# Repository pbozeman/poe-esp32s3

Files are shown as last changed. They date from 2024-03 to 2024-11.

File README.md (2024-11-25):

# POE ESP32S3

POE enabled ESP32S3 dev board with onboard programming via USB-C,
and an OTG USB-A port. The repo contains the Kicad schematic and PCB
design.

It is ok to apply power via USB-C and POE simultaneously. The board
gives preference to the POE, if it is present.

While this can be used as a general purpose POE dev board, I personally
use it to network enable a Aeotec Zwave stick using the ser2net protocol.

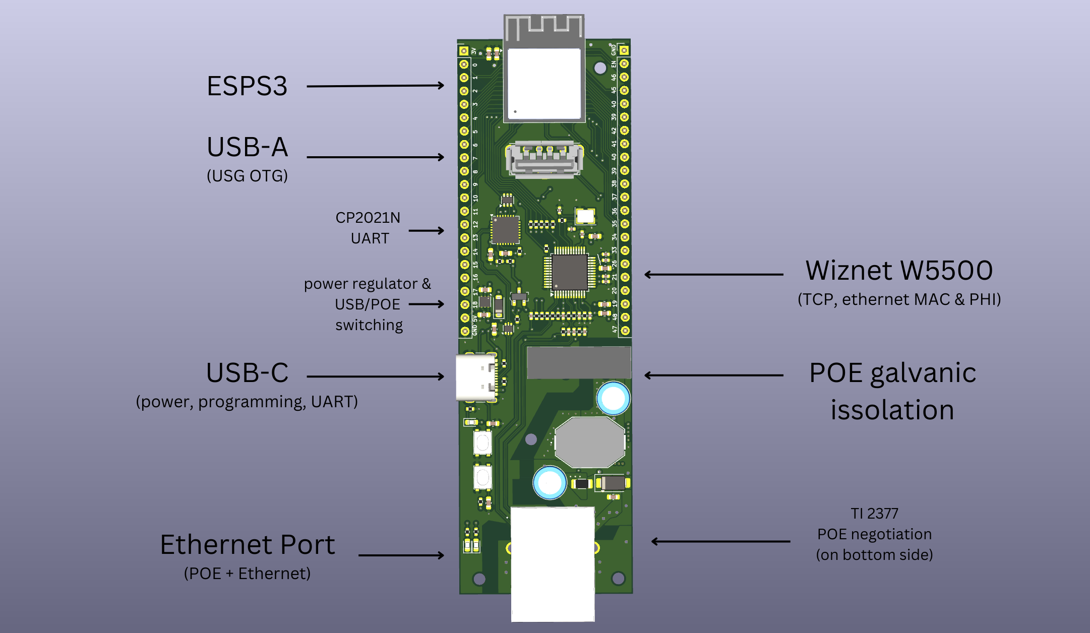
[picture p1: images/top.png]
top_pcb_image top pcb image


## "Inspiration"

I copied the POE schematic and layout directly from [OLIMEX](https://github.com/OLIMEX/ESP32-POE-ISO/blob/master/HARDWARE/ESP32-PoE-ISO-Rev.K/ESP32-PoE-ISO_Rev_K.pdf).

The Wiznet 5500 ethernet to SPI circuit was copied directly from the
[WS5500 reference circuit](https://docs.wiznet.io/img/products/w5500/W5500_ds_v110e.pdf)

Everything else is from the [ES32-S3 reference circuit](https://dl.espressif.com/dl/schematics/SCH_ESP32-S3-DEVKITM-1_V1_20210310A.pdf).

## General Caveats

This was my very first PCB and there is a lot I don't like about both
the schematic and the PCB layout. I'm only making this repo public
because someone on Reddit asked for the Kicad files.

More importantly, the Olimex POE design is very noisy. It's fine for
my use, but I heard from someone else that used an Olimex like design
that it was too noisy to use directly with an ADC.

If I were to do this again, I would base the POE design around Silvertel
POE modules, potentially using them directly. I measured one and it's
power was far less noisy. The entire unit is cheaper than trying to
source individual parts, and they come in form factors that should be easy
to integrate.

## Production and Update Caveats

I don't think part numbers were populated, and this may nor may not
seamlessly export with the JLCPCB exporter. The library management
is likely bad, and there is a possibility that I edited symbols or
footprints directly, without doing so in the library. There might
be non-relative paths in the library configs as well. I hadn't yet
established best practices for any of that back when I did this. So,
updating symbols and footprints might mess up the schematic and PCB.

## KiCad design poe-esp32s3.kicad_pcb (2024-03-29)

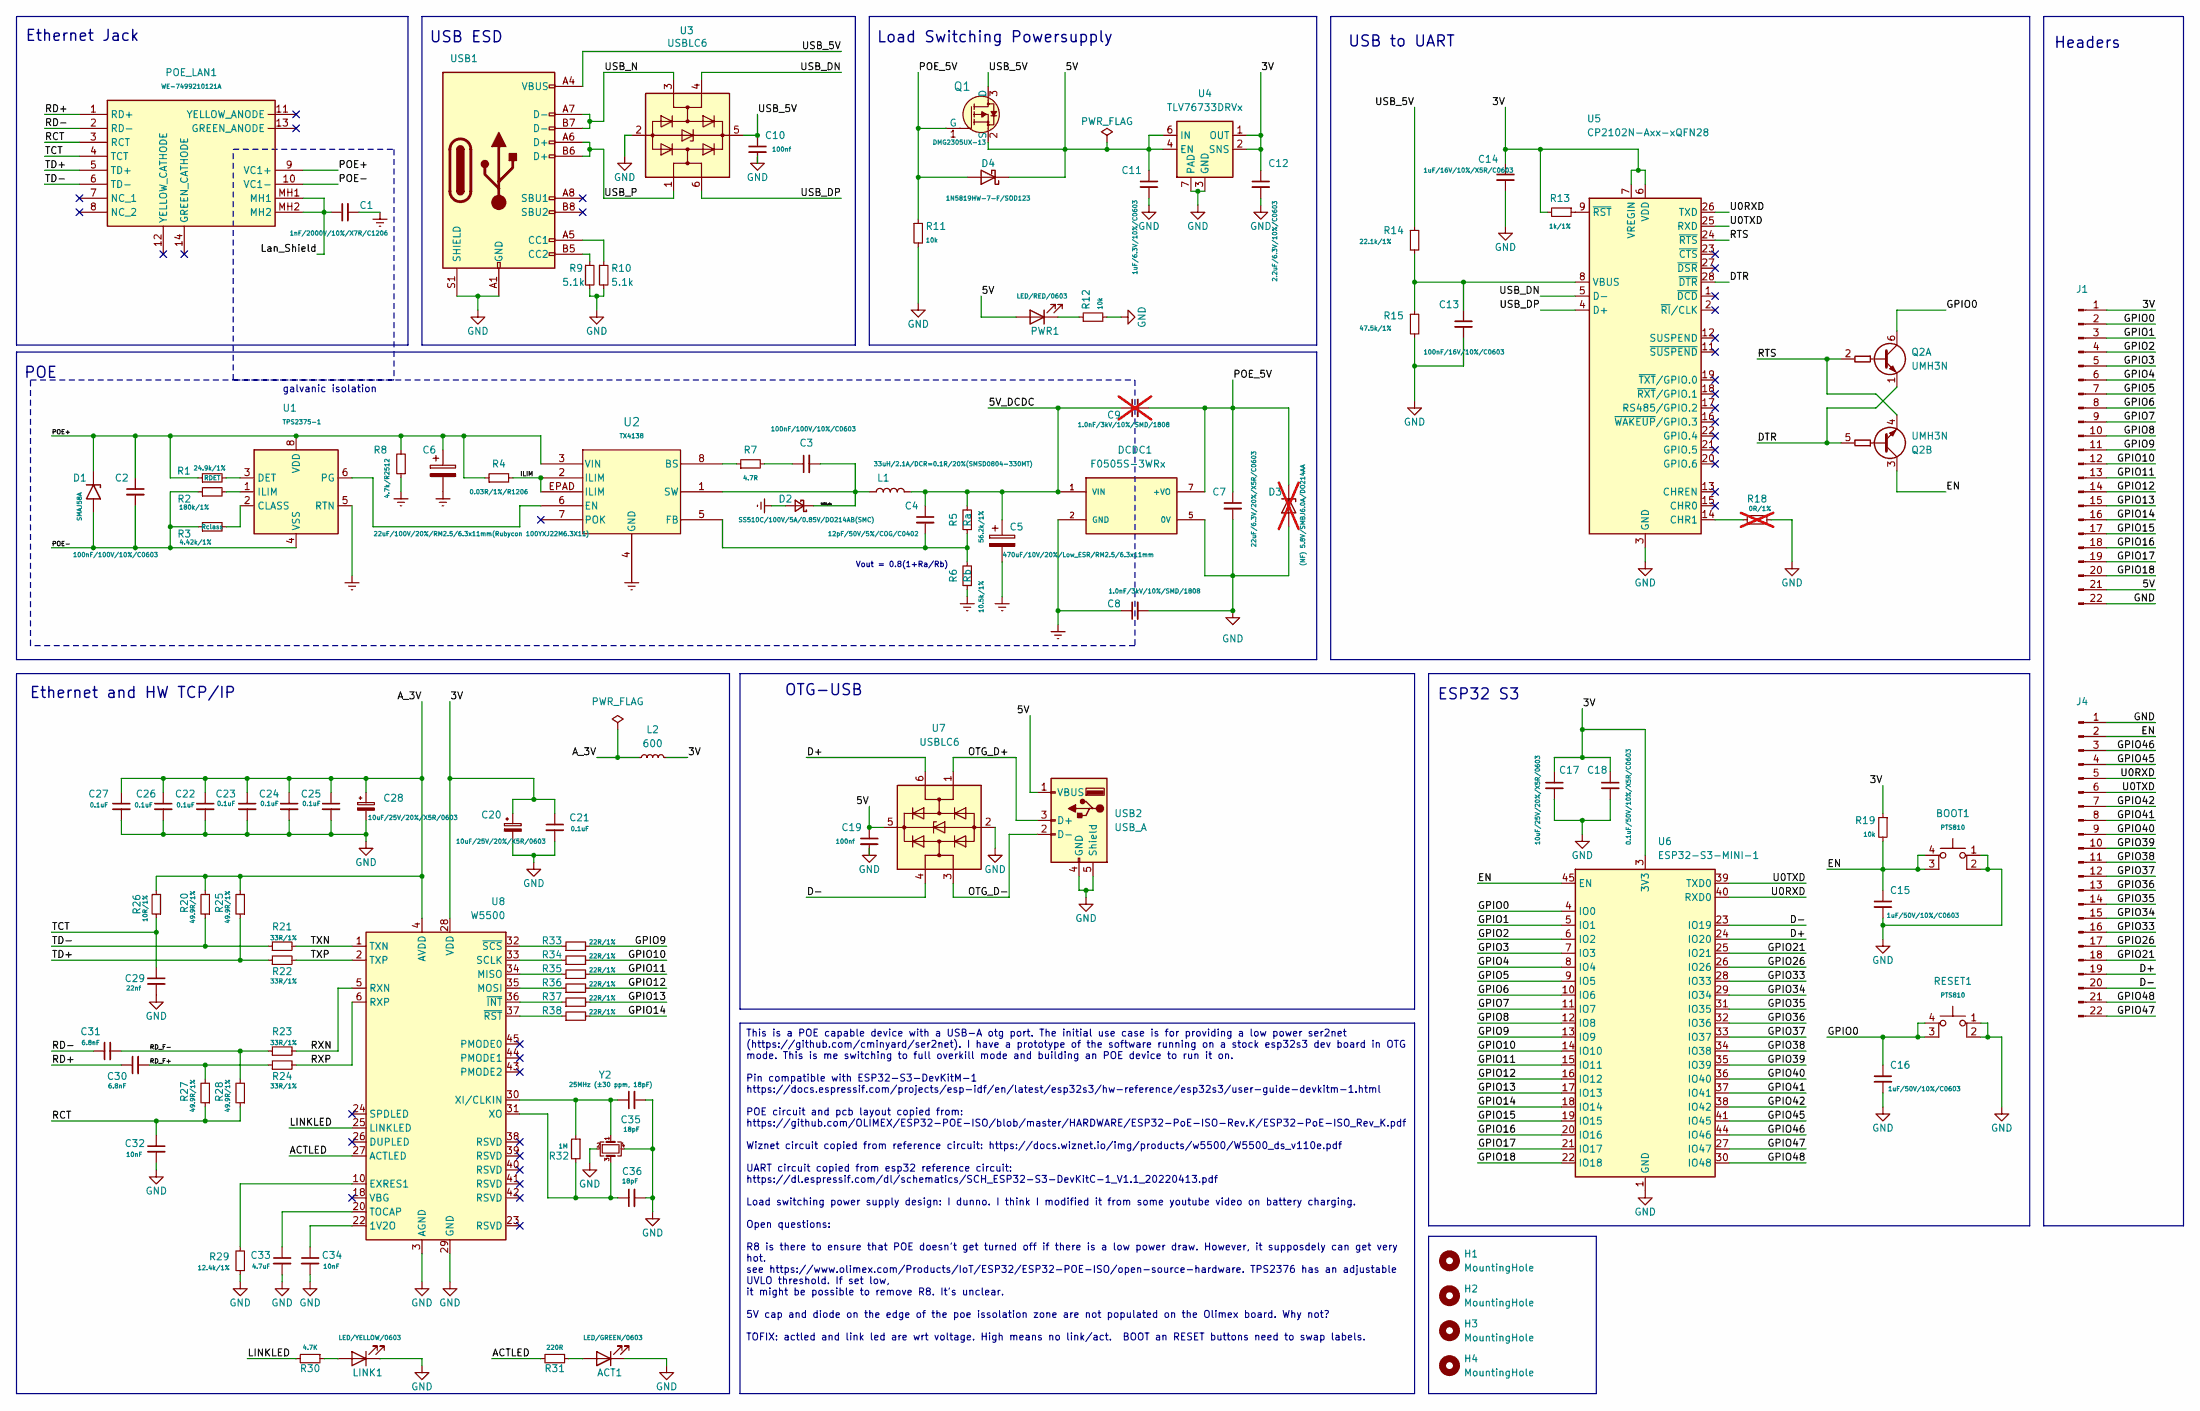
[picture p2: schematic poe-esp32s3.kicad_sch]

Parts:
ACT1: LED/GREEN/0603; LED_0603_1608Metric; MPN 19-21SYGC/S530-E2/TR8
BOOT1: PTS810; SW_SPST_PTS810; MPN PTS810SJG250SMTRLFS
C1: 1nF/2000V/10%/X7R/C1206; C_1206_3216Metric; MPN CC1206MKX7RDBB102
C2, C3: 100nF/100V/10%/C0603; C_0603_1608Metric; MPN CL10B104KC8NNNC
C4: 12pF/50V/5%/COG/C0402; C_0402_1005Metric; MPN 0402CG120J500NT
C5: 470uF/10V/20%/Low_ESR/RM2.5/6.3x11mm; C_Radial_D6.3mm_H11.0mm_P2.50mm; MPN 10YXJ470MFFC(6.3X11)
C6: 22uF/100V/20%/RM2.5/6.3x11mm(Rubycon 100YXJ22M6.3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; C_Radial_D6.3mm_H11.0mm_P2.50mm; MPN 100YXJ22M6.3X11
C7: 22uF/6.3V/20%/X5R/C0603; C_0603_1608Metric; MPN CL10A226MQ8NRNC
C8: 1.0nF/3kV/10%/SMD/1808; C_1808; MPN C1808N102J302T
C9: 1.0nF/3kV/10%/SMD/1808; C_1808; not fitted
C10, C19: 100nf; C_0603_1608Metric; MPN CC0603KRX7R9BB104
C11: 1uF/6.3V/10%/C0603; C_0603_1608Metric; MPN CC0603KRX5R5BB105
C12: 2.2uF/6.3V/10%/C0603; C_0603_1608Metric; MPN 06036D225KAT2A
C13: 100nF/16V/10%/C0603; C_0603_1608Metric; MPN CL10B104KO8NNNC
C14: 1uF/16V/10%/X5R/C0603; C_0603_1608Metric; MPN CL10A105KO8NNNC
C15, C16: 1uF/50V/10%/C0603; C_0603_1608Metric; MPN CL10A105KB8NNNC
C17, C20, C28: 10uF/25V/20%/X5R/0603; C_0603_1608Metric; MPN CL10A106MA8NRNC
C18: 0.1uF/50V/10%/X5R/C0603; C_0603_1608Metric; MPN CC0603KRX7R9BB104
C21, C22, C23, C24, C25, C26, C27: 0.1uF; C_0402_1005Metric; MPN CL05B104KO5NNNC
C29: 22nf; C_0402_1005Metric; MPN 0402B223K500NT
C30, C31: 6.8nF; C_0402_1005Metric; MPN 0402B682K500NT
C32, C34: 10nF; C_0402_1005Metric; MPN 0402B102K500NT
C33: 4.7uF; C_0603_1608Metric; MPN CL10A475KO8NNNC
C35, C36: 18pF; C_0402_1005Metric; MPN 0402CG180J500NT
D1: SMAJ58A; D_SMA; MPN SMAJ58A-E3/5A
D2: SS510C/100V/5A/0.85V/DO214AB(SMC); DO-214AB; MPN SS510C
D3: (NF) 5.8V/SMBJ6.0A/DO214AA; D_SMB; MPN NA; not fitted
D4: 1N5819HW-7-F/SOD123; D_SOD-123; MPN 1N5819HW-7-F
DCDC1: F0505S-3WRx; CONV_F0505S-1WR3; PARTREV 2021.12.28-A/6
H1, H2, H3, H4: MountingHole; MountingHole_2.2mm_M2; MPN NA
J1, J4: PinHeader_1x22_P2.54mm_Vertical; MPN NA
L1: 33uH/2.1A/DCR=0.1R/20%(SMSD0804-330MT); IND_IDC-5020_VIS; MPN SMSD0804-330MT
L2: 600; C_0603_1608Metric; MPN MLB1608F-121T
LINK1: LED/YELLOW/0603; LED_0603_1608Metric; MPN 19-213/Y2C-CQ2R2L/3T(CY)
POE_LAN1: WE-7499210121A; 7499210121A; Manufacturer_Part_Number 7499210121A; Mouser Part Number 710-7499210121A
PWR1: LED/RED/0603; LED_0603_1608Metric; MPN KT-0603R
Q1: DMG2305UX-13; SOT-23-3; MPN DMG2305UX-13; Digi-Key_PN DMG2305UX-13DICT-ND
Q2: UMH3N; SOT-363_SC-70-6; MPN UMH3N
R1: 24.9k/1%; R_0402_1005Metric; MPN 0402WGF2492TCE
R2: 180k/1%; R_0402_1005Metric; MPN CR0402FF1803G
R3: 4.42k/1%; R_0402_1005Metric; MPN CR0402FF4421G
R4: 0.03R/1%/R1206; R_1206_3216Metric; MPN 1206W3F300MT5E
R5: 56.2k/1%; R_0402_1005Metric; MPN RC-02W5622FT
R6: 10.5k/1%; R_0402_1005Metric; MPN RC0402FR-0710K5L
R7: 4.7R; R_0402_1005Metric; MPN 0402WGF470KTCE
R8: 4.7k/R2512; R_2512_6332Metric; MPN RMC25124.7K1%N
R9, R10: 5.1k; R_0402_1005Metric; MPN 0402WGF5101TCE
R11, R12, R19: 10k; R_0402_1005Metric; MPN 0402WGF1002TCE
R13: 1k/1%; R_0402_1005Metric; MPN 0402WGF1001TCE
R14: 22.1k/1%; R_0402_1005Metric; MPN RC0402FR-0722K1L
R15: 47.5k/1%; R_0402_1005Metric; MPN 0402WGF4752TCE
R18: 0R/1%; R_0603_1608Metric; MPN 0603WAF0000T5E; not fitted
R20, R25, R27, R28: 49.9R/1%; R_0402_1005Metric; MPN 0402WGF499JTCE
R21, R22, R23, R24: 33R/1%; R_0402_1005Metric; MPN 0402WGF330JTCE
R26: 10R/1%; R_0402_1005Metric; MPN 0402WGF100JTCE
R29: 12.4k/1%; R_0402_1005Metric; MPN RC0402FR-0712K4L
R30: 4.7K; R_0402_1005Metric; MPN 0402WGF4701TCE
R31: 220R; R_0402_1005Metric; MPN 0402WGF2200TCE
R32: 1M; R_0402_1005Metric; MPN CRG0402F1M0
R33, R34, R35, R36, R37, R38: 22R/1%; R_0402_1005Metric; MPN 0402WGF220JTCE
RESET1: PTS810; SW_SPST_PTS810; MPN PTS810SJG250SMTRLFS
U1: TPS2375-1; TSSOP-8_4.4x3mm_P0.65mm; MPN TPS2375PW-1
U2: TX4138; tx4138-ESOIC8_XDS; MPN TX4138
U3, U7: USBLC6; SOT-666; MPN USBLC6-2P6
U4: TLV76733DRVx; WSON-6-1EP_2x2mm_P0.65mm_EP1x1.6mm_ThermalVias; MPN TLV76733DRVR
U5: CP2102N-Axx-xQFN28; QFN-28-1EP_5x5mm_P0.5mm_EP3.35x3.35mm; MPN CP2102N-A02-GQFN28R
U6: ESP32-S3-MINI-1; ESP32-S2-MINI-1; MPN ESP32-S3-MINI-1-N8
U8: W5500; LQFP-48_7x7mm_P0.5mm; MPN W5500
USB1: USB_C_Receptacle_USB2.0_16P; USB_C_Receptacle_GCT_USB4105-xx-A_16P_TopMnt_Horizontal; MPN GT-USB-7004
USB2: USB_A; usb-a-U-A-24DD-W-9; MPN U-A-24DD-W-9
Y2: 25MHz (±30 ppm, 18pF); Crystal_SMD_3225-4Pin_3.2x2.5mm; MPN S322525M18PF10PPM

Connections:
/3V: C12.1, C14.1, C17.1, C18.1, C20.1, C21.1, J1.1, L2.2, R13.2, R19.1, U4.1 (OUT), U4.2 (SNS), U5.6 (VDD), U5.7 (VREGIN), U6.3 (3V3), U8.28 (VDD)
/5V: C11.1, C19.1, D4.1 (K), J1.21, PWR1.2 (A), Q1.2 (S), U4.4 (EN), U4.6 (IN), U7.5 (VBUS), USB2.1 (VBUS)
/5V_DCDC: C4.1, C5.1, C9.1, DCDC1.1 (VIN), L1.2, R5.2
/4138_da: C3.2, D2.1 (K), L1.1, U2.1 (SW)
/ACTLED: R31.2, U8.27 (ACTLED)
/A_3V: C22.1, C23.1, C24.1, C25.1, C26.1, C27.1, C28.1, L2.1, R20.2, R25.2, R26.2, U8.4 (AVDD), U8.8 (AVDD), U8.11 (AVDD), U8.15 (AVDD), U8.17 (AVDD), U8.21 (AVDD)
/D+: J4.19, U6.24 (IO20), U7.6 (I/O1)
/D-: J4.20, U6.23 (IO19), U7.4 (I/O2)
/DTR: Q2.1 (E1), Q2.5 (B2), U5.28 (~DTR)
/EN: BOOT1.3 (K), BOOT1.4 (A), C15.1, J4.2, Q2.3 (C2), R19.2, U6.45 (EN)
/GPIO0: C16.1, J1.2, Q2.6 (C1), RESET1.3 (K), RESET1.4 (A), U6.4 (IO0)
/GPIO1: J1.3, U6.5 (IO1)
/GPIO2: J1.4, U6.6 (IO2)
/GPIO3: J1.5, U6.7 (IO3)
/GPIO4: J1.6, U6.8 (IO4)
/GPIO5: J1.7, U6.9 (IO5)
/GPIO6: J1.8, U6.10 (IO6)
/GPIO7: J1.9, U6.11 (IO7)
/GPIO8: J1.10, U6.12 (IO8)
/GPIO9: J1.11, R33.2, U6.13 (IO9)
/GPIO10: J1.12, R34.2, U6.14 (IO10)
/GPIO11: J1.13, R35.2, U6.15 (IO11)
/GPIO12: J1.14, R36.2, U6.16 (IO12)
/GPIO13: J1.15, R37.2, U6.17 (IO13)
/GPIO14: J1.16, R38.2, U6.18 (IO14)
/GPIO15: J1.17, U6.19 (IO15)
/GPIO16: J1.18, U6.20 (IO16)
/GPIO17: J1.19, U6.21 (IO17)
/GPIO18: J1.20, U6.22 (IO18)
/GPIO21: J4.18, U6.25 (IO21)
/GPIO26: J4.17, U6.26 (IO26)
/GPIO33: J4.16, U6.28 (IO33)
/GPIO34: J4.15, U6.29 (IO34)
/GPIO35: J4.14, U6.31 (IO35)
/GPIO36: J4.13, U6.32 (IO36)
/GPIO37: J4.12, U6.33 (IO37)
/GPIO38: J4.11, U6.34 (IO38)
/GPIO39: J4.10, U6.35 (IO39)
/GPIO40: J4.9, U6.36 (IO40)
/GPIO41: J4.8, U6.37 (IO41)
/GPIO42: J4.7, U6.38 (IO42)
/GPIO45: J4.4, U6.41 (IO45)
/GPIO46: J4.3, U6.44 (IO46)
/GPIO47: J4.22, U6.27 (IO47)
/GPIO48: J4.21, U6.30 (IO48)
/ILIM: R4.2, U2.2 (ILIM), U2.EPAD (ILIM)
/LINKLED: R30.2, U8.25 (LINKLED)
/Lan_Shield: C1.1, POE_LAN1.MH1, POE_LAN1.MH2
/OTG_D+: U7.1 (I/O1), USB2.3 (D+)
/OTG_D-: U7.3 (I/O2), USB2.2 (D-)
/POE+: C2.1, C6.1, D1.1 (A1), POE_LAN1.9 (VC1+), R1.1, R4.1, R8.2, U1.8 (VDD), U2.3 (VIN)
/POE-: C2.2, D1.2 (A2), POE_LAN1.10 (VC1-), R2.1, R3.1, U1.4 (VSS)
/POE_5V: C7.1, C9.2, D3.1 (K), D4.2 (A), DCDC1.7 (+VO), Q1.1 (G), R11.1
/RCT: C32.1, POE_LAN1.3 (RCT), R27.1, R28.1
/RD+: C30.1, POE_LAN1.1 (RD+)
/RD-: C31.1, POE_LAN1.2 (RD-)
/RD_F+: C30.2, R24.1, R27.2
/RD_F-: C31.2, R23.1, R28.2
/RTS: Q2.2 (B1), Q2.4 (E2), U5.24 (~RTS)
/RXN: R23.2, U8.5 (RXN)
/RXP: R24.2, U8.6 (RXP)
/TCT: C29.1, POE_LAN1.4 (TCT), R26.1
/TD+: POE_LAN1.5 (TD+), R22.1, R25.1
/TD-: POE_LAN1.6 (TD-), R20.1, R21.1
/TXN: R21.2, U8.1 (TXN)
/TXP: R22.2, U8.2 (TXP)
/U0RXD: J4.5, U5.26 (TXD), U6.40 (RXD0)
/U0TXD: J4.6, U5.25 (RXD), U6.39 (TXD0)
/USB_5V: C10.1, Q1.3 (D), R14.1, U3.5 (VBUS), USB1.A4 (VBUS), USB1.A9 (VBUS), USB1.B4 (VBUS), USB1.B9 (VBUS)
/USB_DN: U3.4 (I/O2), U5.5 (D-)
/USB_DP: U3.6 (I/O1), U5.4 (D+)
/USB_N: U3.3 (I/O2), USB1.A7 (D-), USB1.B7 (D-)
/USB_P: U3.1 (I/O1), USB1.A6 (D+), USB1.B6 (D+)
Earth: C1.2, C5.2, C6.2, C8.1, D2.2 (A), DCDC1.2 (GND), R6.1, R8.1, U1.5 (RTN), U2.4 (GND)
GND: ACT1.1 (K), BOOT1.1, BOOT1.2, C7.2, C8.2, C10.2, C11.2, C12.2, C13.2, C14.2, C15.2, C16.2, C17.2, C18.2, C19.2, C20.2, C21.2, C22.2, C23.2, C24.2, C25.2, C26.2, C27.2, C28.2, C29.2, C32.2, C33.2, C34.2, C35.2, C36.2, D3.2 (A), DCDC1.5 (0V), J1.22, J4.1, LINK1.1 (K), R9.2, R10.2, R11.2, R12.2, R15.2, R18.2, R29.1, RESET1.1, RESET1.2, U3.2 (GND), U4.3 (GND), U4.5 (GND), U4.7 (PAD), U5.3 (GND), U5.29 (GND), U6.1 (GND), U6.2 (GND), U6.42 (GND), U6.43 (GND), U6.46 (GND), U6.47 (GND), U6.48 (GND), U6.49 (GND), U6.50 (GND), U6.51 (GND), U6.52 (GND), U6.53 (GND), U6.54 (GND), U6.55 (GND), U6.56 (GND), U6.57 (GND), U6.58 (GND), U6.59 (GND), U6.60 (GND), U6.61 (GND), U6.62 (GND), U6.63 (GND), U6.64 (GND), U6.65 (GND), U7.2 (GND), U8.3 (AGND), U8.9 (AGND), U8.14 (AGND), U8.16 (AGND), U8.19 (AGND), U8.29 (GND), U8.48 (AGND), USB1.A1 (GND), USB1.A12 (GND), USB1.B1 (GND), USB1.B12 (GND), USB1.S1 (SHIELD), USB2.4 (GND), USB2.5 (Shield), Y2.2, Y2.4
unnamed: ACT1.2 (A), R31.1
unnamed: C3.1, R7.2
unnamed: LINK1.2 (A), R30.1
unnamed: PWR1.1 (K), R12.1
unnamed: R3.2, U1.2 (CLASS)
unnamed: R1.2, U1.3 (DET)
unnamed: R2.2, U1.1 (ILIM)
unnamed: U1.6 (PG), U2.6 (EN)
unnamed: R7.1, U2.8 (BS)
unnamed: C4.2, R5.1, R6.2, U2.5 (FB)
unnamed: R18.1, U5.14 (CHR1)
unnamed: C13.1, R14.2, R15.1, U5.8 (VBUS)
unnamed: R13.1, U5.9 (~RST)
unnamed: C34.1, U8.22 (1V2O)
unnamed: R29.2, U8.10 (EXRES1)
unnamed: R35.1, U8.34 (MISO)
unnamed: R36.1, U8.35 (MOSI)
unnamed: R34.1, U8.33 (SCLK)
unnamed: C33.1, U8.20 (TOCAP)
unnamed: C35.1, R32.1, U8.30 (XI/CLKIN), Y2.1
unnamed: C36.1, R32.2, U8.31 (XO), Y2.3
unnamed: R37.1, U8.36 (~INT)
unnamed: R38.1, U8.37 (~RST)
unnamed: R33.1, U8.32 (~SCS)
unnamed: R10.1, USB1.A5 (CC1)
unnamed: R9.1, USB1.B5 (CC2)

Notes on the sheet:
This is a POE capable device with a USB-A otg port. The initial use case is for providing a low power ser2net (https://github.com/cminyard/ser2net). I have a prototype of the software running on a stock esp32s3 dev board in OTG mode. This is me switching to full overkill mode and building an POE de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
Load Switching Powersupply
Vout = 0.8(1+Ra/Rb)
galvanic isolation
USB to UART
OTG-USB
POE
Ethernet and HW TCP/IP
ESP32 S3
USB ESD
Ethernet Jack
Headers

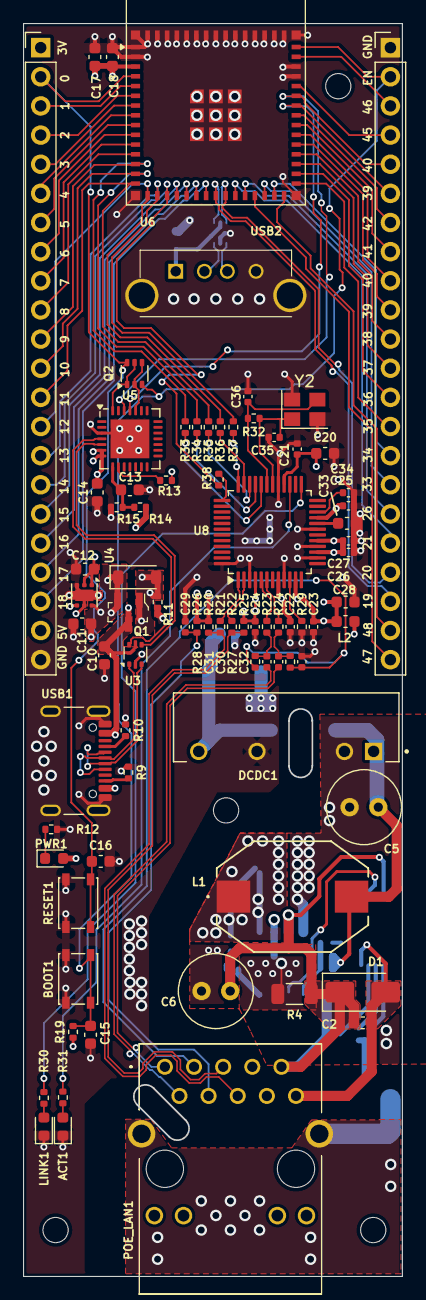
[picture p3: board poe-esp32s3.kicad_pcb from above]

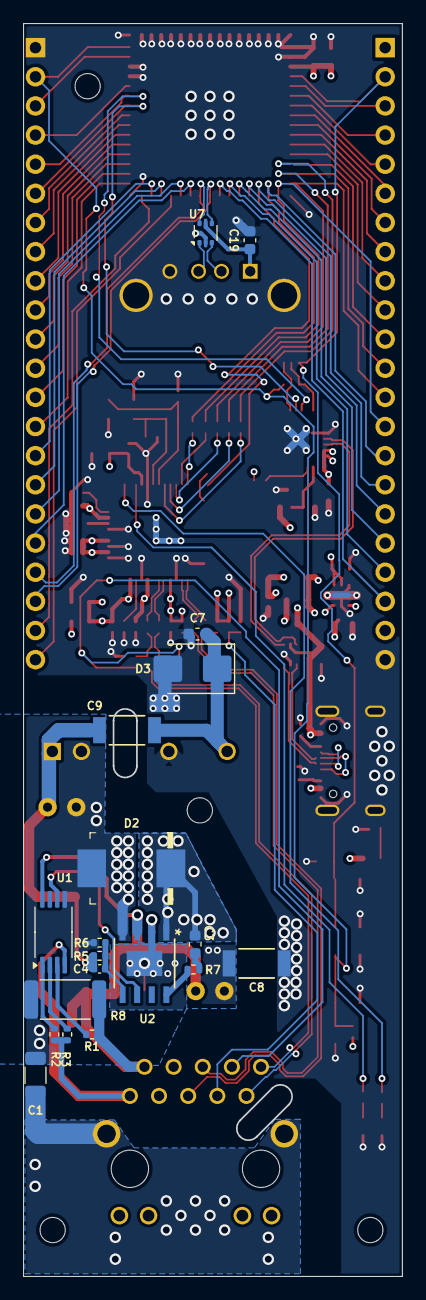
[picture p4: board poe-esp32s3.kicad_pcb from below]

Board: 4 copper layers, 33.0 x 109.2 mm, 103 parts (19 on the bottom side), 100 nets.
